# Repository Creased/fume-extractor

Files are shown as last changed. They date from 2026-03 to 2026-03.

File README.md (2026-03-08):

# Soldering Fume Extraction System

This project provides a complete set of 3D printable adapters and components to build a custom, high-efficiency fume extractor and filtration system. It integrates a VIVOSUN inline fan, a MANN-FILTER cabin air filter, and a standard 2-1/2" flexible dust collection hose.

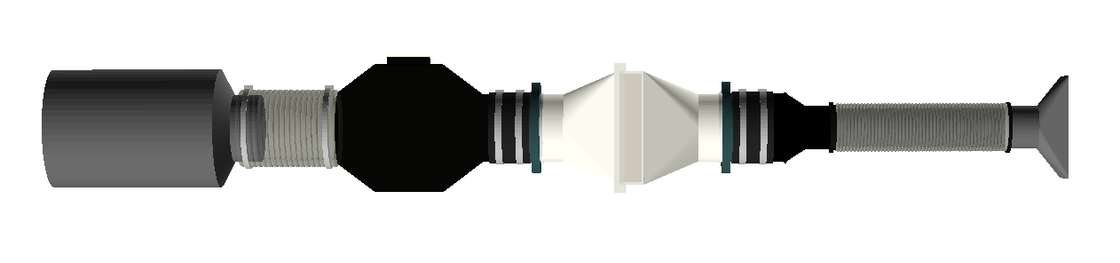
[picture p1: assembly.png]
assembly


## Bill of Materials (BOM)

### Commercial Components

| Component | Amazon FR |
| :--- | :--- |
| **VIVOSUN Inline Duct Fan Kit** (100mm, 357m³/h, Speed Controller, Carbon Filter & 240cm Duct, AeroZesh T4) | [Link](https://www.amazon.fr/dp/B0CBPDTSKS) |
| **MANN-FILTER FP 21 000-2** Cabin Air Filter (150x158x32mm) | [Link](https://www.amazon.fr/dp/B011KJG19S) |
| **PowerTec 70208V** 2-1/4" Flexible Dust Collection Hose Kit (Black, 5.7cm) | [Link](https://www.amazon.fr/dp/B09T2B5ZM2) |
| **POWERTEC 70149-P2** 4-Inch Key Hose Clamps (2 Pack) | [Link](https://www.amazon.fr/dp/B09NR8172H) |

*Note: You do not need to buy the PowerTec nozzle separately, as a customized 3D printable rectangular nozzle is provided in this repository.*

### Hardware
* **M3 Screws & Threaded Inserts**: For assembling the filter box and adapters. [Bolt Nut BT3 on AliExpress](https://fr.aliexpress.com/item/1005007615031481.html) (Requires M3x14mm Socket Head Cap Screws and M3x5mm Threaded Inserts with 4.16mm OD).

### 3D Printed Parts

The system requires the following 3D printed components:

1. **Duct Adapters** (`duct_adapter_direct.scad` & `duct_adapter.scad`)
   - **Quantity**: 2
   - **Usage**: You will generally use two **direct** variants (`duct_adapter_direct.scad`). The first adapter connects directly to the inline fan. The second adapter connects the filter box to the duct reducer. (Note: use the **threaded** variant `duct_adapter.scad` only if you wish to detach the pre-filter box from the fan and add a flexible duct section in between them).
   - Both adapters clamp around the filter box flanges using the split capture rings, providing a robust surface for the flexible hose clamps.
2. **Duct Reducer** (`duct_reducer.scad`)
   - Steps down the dimension from the 4" (100mm) top adapter to the 2-1/2" flex hose.
3. **Rectangular Nozzle & Grid** (`rectangular_nozzle.scad`)
   - Replicates the PowerTec opening but features an integrated friction-fit anti-debris grid that stops large particles without catching soldering fumes.
4. **Inline Filter Box** (`inline_filter_box.scad`)
   - The central two-part housing for the MANN-FILTER FP 21 000-2.

## Assembly Instructions

> **Tip:** Open `assembly.scad` in OpenSCAD for an exploded 3D view of how all components stack together!

1. **Print**: 3D print all `.scad` components (exporting to STL/3MF).
2. **Filter Box**: Insert the MANN-FILTER into the inline filter box housing and secure the lid with M3 hardware.
3. **Adapters**: Attach the split capture ring halves behind the filter flanges, and bolt on the adapter sleeves over them.
4. **Main Connections**: Use the POWERTEC flex hose clamps to securely connect the adapters to the duct reducer (top) and the Vivosun inline fan (bottom).
5. **Hose & Nozzle**: Push the 2-1/2" flexible hose onto the top of the duct reducer. Attach the rectangular nozzle (with its grid insert pushed into the base) to the other end of the hose.

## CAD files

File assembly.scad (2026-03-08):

// Full System Assembly
// Visualizes the complete vertical stack from suction nozzle to exhaust.

use <inline_filter_box.scad>
use <duct_adapter_direct.scad>
use <duct_reducer.scad>
use <rectangular_nozzle.scad>

$fn = 60;

// --- Options ---
assemble_all = false; // Set to true to collapse the exploded view

// Geometry Calculations
e = assemble_all ? 0 : 50;

// Filter Box (Anchor)
filter_main_z = 0;
z_filter      = filter_main_z + 3 + e;
lid_z         = filter_main_z + 35 + 2*e;

// Top Stack
top_adapter_ring_z = lid_z + 118 + 3*e;
top_adapter_z      = lid_z + 118 + 4*e;

top_joint_z        = top_adapter_z + 45 + 5*e;
top_coupling_z     = top_joint_z;
fan_z              = top_joint_z + 6*e;

exhaust_z          = fan_z + 260 + 7*e; 
carbon_filter_z    = exhaust_z + 110 + 8*e;

// Bottom Stack
bottom_adapter_ring_z = filter_main_z - 115 - 1*e;
bottom_adapter_z      = filter_main_z - 115 - 2*e;

bottom_joint_z        = bottom_adapter_z - 45 - 3*e;
bottom_coupling_z     = bottom_joint_z;

reducer_z             = bottom_joint_z - 4*e;
reducer_small_z       = reducer_z - 113.5;
top_coupler_z         = reducer_small_z + 45 - 5*e;
hose_top              = top_coupler_z - 52 - 6*e;
hose_length           = 250;
hose_bottom           = hose_top - hose_length;

bottom_coupler_z      = hose_bottom - 52 - 7*e;
nozzle_z              = bottom_coupler_z + 45 - 8*e;


// Carbon Filter
translate([0, 0, carbon_filter_z])
    carbon_filter();


// Exhaust Flex Hose (100mm)
color("DimGray", 0.4) {
    translate([0, 0, exhaust_z])
        flex_hose(d = 103, h = 150, pitch = 8); 
}
translate([0, 0, exhaust_z + 5]) metal_clamp(115);
translate([0, 0, exhaust_z + 150 - 25]) metal_clamp(115);

// Inline Fan
translate([0, 0, fan_z]) 
    vivosun_fan();


// Top Rubber Coupling
translate([0, 0, top_coupling_z]) rubber_coupling();


// Top Adapter
color("DarkSlateGray") {
    translate([0, 0, top_adapter_z]) adapter_sleeve();
    
    translate([0, 0, top_adapter_ring_z]) {
        capture_ring_half();
        mirror([1, 0, 0]) capture_ring_half();
    }
}


// Inline Filter Box
color("Wheat") {
    translate([-158/2, -150/2, z_filter]) 
        cube([158, 150, 32]);
}

color("White", 0.6) {
    translate([0, 0, filter_main_z]) build_main_body(); 
    translate([0, 0, lid_z])         build_lid(); 
}


// Bottom Adapter
color("DarkSlateGray") {
    translate([0, 0, bottom_adapter_z]) rotate([180, 0, 0]) adapter_sleeve();
    
    translate([0, 0, bottom_adapter_ring_z]) rotate([180, 0, 0]) {
        capture_ring_half();
        mirror([1, 0, 0]) capture_ring_half();
    }
}


// Bottom Rubber Coupling
translate([0, 0, bottom_coupling_z]) rubber_coupling();


// Duct Reducer (100mm to 63mm)
color("Black") {
    translate([0, 0, reducer_z])
        rotate([180, 0, 0]) duct_reducer();
}


// Suction Flex Hose (63.1mm)
color("DimGray", 0.4) {
    translate([0, 0, hose_bottom])
        flex_hose(d = 63.6, h = hose_length, pitch = 5); 
}

// Quick Couplers
translate([0, 0, top_coupler_z]) quick_coupler();
translate([0, 0, bottom_coupler_z]) rotate([180, 0, 0]) quick_coupler();


// Rectangular Nozzle
color("DimGray") {
    translate([0, 0, nozzle_z]) rotate([180, 0, 0]) {
        nozzle_body();
        color("Orange")
        translate([0, 0, 40.1 - 4]) grid_insert(); // Insert is positioned relative to base
    }
}


// Helper Modules

module flex_hose(d, h, pitch) {
    loops = floor(h / pitch);
    for (i = [0 : loops - 1]) {
        translate([0, 0, i * pitch])
            rotate_extrude()
            translate([d/2, 0])
                circle(d = pitch * 1.5, $fn = 16);
    }
}

module vivosun_fan() {
    color("Black", 0.85) {
        // Bottom flange
        cylinder(d=100, h=40);
        // Bottom transition
        translate([0,0,40]) cylinder(d1=100, d2=190, h=60);
        // Main body (contains the motor)
        translate([0,0,100]) cylinder(d=190, h=100);
        // Top transition
        translate([0,0,200]) cylinder(d1=190, d2=100, h=60);
        // Top flange
        translate([0,0,260]) cylinder(d=100, h=40);
        
        // Controller/logo box on the side
        color("DarkSlateGray") 
        translate([80, -25, 120]) cube([25, 50, 60]);
    }
}

module carbon_filter() {
    color("DimGray") {
        // Bottom Flange
        cylinder(d=100, h=40);
        // Transition
        translate([0, 0, 40]) cylinder(d1=100, d2=175, h=20);
        // Main perforated body
        color("Silver")
        translate([0, 0, 60]) cylinder(d=175, h=240);
        // Top cap
        translate([0, 0, 300]) cylinder(d=175, h=10);
    }
}

module rubber_coupling() {
    // 100mm ID, ~106mm OD, 60mm height
    translate([0, 0, -30]) { // Center it vertically
        color("#222222") 
        difference() {
            cylinder(d=106, h=60);
            translate([0,0,-1]) cylinder(d=100.2, h=62);
        }
        // Metal bands
        color("Silver") {
            translate([0,0, 10]) difference() { cylinder(d=108, h=10); translate([0,0,-1]) cylinder(d=105, h=12); }
            translate([0,0, 40]) difference() { cylinder(d=108, h=10); translate([0,0,-1]) cylinder(d=105, h=12); }
            // Worm gear housing representations
            translate([53, 0, 15]) rotate([90,0,0]) cube([8, 12, 10], center=true);
            translate([53, 0, 45]) rotate([90,0,0]) cube([8, 12, 10], center=true);
        }
    }
}

module metal_clamp(id=105) {
    color("Silver") {
        difference() { cylinder(d=id+4, h=8); translate([0,0,-0.1]) cylinder(d=id, h=8.2); }
        // Worm gear screw housing
        translate([id/2 + 2, 0, 4]) rotate([90,0,0]) cube([8, 12, 10], center=true);
    }
}

module quick_coupler() {
    color("#111111") {
        // Upper smooth insert (goes into duct_reducer / nozzle)
        translate([0, 0, -45]) cylinder(d=58, h=45);
        
        // Stopper flange
        translate([0, 0, -50]) cylinder(d=75, h=5);
        translate([0, 0, -52]) cylinder(d=67, h=2);
        
        // Lower threaded part (screws onto the hose)
        translate([0, 0, -85]) cylinder(d=67, h=33);
    }
}

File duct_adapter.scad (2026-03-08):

// Duct Adapter - 3-Piece System (Threaded)
// ==============================================
// Problem: Printed filter box has a 106mm OD flange with a 110mm lip.
//          The 100mm flex duct can't slide over the lip.
//
// Solution:
//   1. SPLIT CAPTURE RING (x2 halves) - Fits around the flange behind
//      the lip. Threaded inserts on the back face.
//   2. ADAPTER SLEEVE - Bolts through its flange plate into the ring
//      inserts, holding both ring halves AND the sleeve in place.
//      The flex duct screws OVER the sleeve tube via spiral thread.
//
// The sleeve bolts span BOTH ring halves, so no lugs are needed!

// --- Existing printed part dimensions ---
existing_flange_od = 106;     // Flange tube OD
existing_lip_od = 110;        // Retention lip OD
existing_lip_length = 5;      // Lip axial length
existing_flange_length = 35;  // Total flange length (ghost only)

// --- General ---
clearance = 0.4;
wall = 3;

// --- Capture Ring ---
ring_body_width = 12;         // Radial wall thickness
ring_depth = 12;              // Total axial depth (tuned for 14mm screws)
groove_depth = 6;             // Groove depth for the lip

// --- Adapter Sleeve ---
duct_diameter = 100;
duct_fit_clearance = 3;       // Tube = 97mm, slides easily into 100mm duct
sleeve_length = 40;
sleeve_wall = 3;
sleeve_flange = 5;            // Flange plate thickness (must be > screw_head_depth)

// --- Thread on sleeve tube (for screwing the duct on) ---
thread_pitch = 12;            // Matches spacing between duct wire guides
thread_ridge_height = 1.5;    // Ridge OD = 97 + 2*1.5 = 100mm, matches duct ID exactly
thread_turns = 3;             // Number of spiral turns
thread_width = 6;             // Cross-section width of the ridge (leaves 6mm gap in 12mm pitch)

// --- Hardware ---
bolt_hole_diameter = 3.5;
insert_diameter = 4.16;
insert_depth = 5;
screw_head_diameter = 5.3;
screw_head_depth = 3;
num_sleeve_bolts = 6;         // MUST be even so bolts are symmetric on both halves

$fn = 100;

// --- Calculated Dimensions ---
ring_back_id = existing_flange_od + clearance;
ring_front_id = existing_lip_od + clearance;
ring_od = ring_front_id + 2 * ring_body_width;

sleeve_od = duct_diameter - duct_fit_clearance;
sleeve_id = sleeve_od - 2 * sleeve_wall;
// Bolt circle sits in the middle of the ring wall
sleeve_bolt_circle_r = (ring_front_id + ring_od) / 4; // radius, not diameter

// --- Display Mode ---
show_assembled = false;        // true = verify fit, false = print layout

if (show_assembled) {
    // Ghost of the existing flange (transparent reference)
    %ghost_flange();

    // Ring halves: assembled behind the lip
    translate([0, 0, -(ring_depth - groove_depth)]) {
        capture_ring_half();
        mirror([1, 0, 0]) capture_ring_half();
    }

    // Sleeve: bolts onto the ring front face
    translate([0, 0, groove_depth])
        adapter_sleeve();

} else {
    // Print layout
    translate([0, ring_od/2 + 10, 0]) capture_ring_half();
    translate([0, -(ring_od/2 + 10), 0]) mirror([0, 1, 0]) capture_ring_half();
    translate([ring_od + 30, 0, 0]) adapter_sleeve();
}


// ==========================================
// MODULES
// ==========================================

// One half of the capture ring (semicircle, X+ side)
module capture_ring_half() {
    difference() {
        union() {
            // Back section: narrower bore, hooks behind the lip
            half_ring(ring_back_id, ring_od, ring_depth - groove_depth);

            // Front section: wider bore, accommodates the lip
            translate([0, 0, ring_depth - groove_depth])
                half_ring(ring_front_id, ring_od, groove_depth);
        }

        // Sleeve bolt holes through the ring body.
        // Inserts on BACK face (Z=0), clearance from insert to front.
        for (i = [0 : num_sleeve_bolts - 1]) {
            angle = i * (360 / num_sleeve_bolts);
            bx = sleeve_bolt_circle_r * cos(angle);
            by = sleeve_bolt_circle_r * sin(angle);
            if (bx > 0.1) {
                // Insert hole on back face (Z=0)
                translate([bx, by, -0.1])
                    cylinder(d = insert_diameter, h = insert_depth + 0.1);
                // Clearance hole from insert to front face
                translate([bx, by, insert_depth])
                    cylinder(d = bolt_hole_diameter, h = ring_depth - insert_depth + 0.1);
            }
        }
    }
}

// Helper: a semicircular ring (X+ half only)
module half_ring(id, od, h) {
    difference() {
        cylinder(d = od, h = h);
        translate([0, 0, -0.1])
            cylinder(d = id, h = h + 0.2);
        // Remove X- half
        translate([-od, -od/2, -0.1])
            cube([od, od, h + 0.2]);
    }
}

// Adapter sleeve: flange + threaded tube. Bolts hold ring halves together.
module adapter_sleeve() {
    difference() {
        union() {
            // Flange plate (spans both ring halves)
            cylinder(d = ring_od, h = sleeve_flange);

            // Tube for flex duct
            translate([0, 0, sleeve_flange])
                cylinder(d = sleeve_od, h = sleeve_length);

            // Spiral thread on the tube (duct screws on by twisting)
            translate([0, 0, sleeve_flange])
                spiral_thread(sleeve_od, thread_pitch, thread_ridge_height, thread_width, thread_turns);
        }

        // Hollow centre
        translate([0, 0, -0.1])
            cylinder(d = sleeve_id, h = sleeve_flange + sleeve_length + 0.2);

        // Bolt holes (clearance + counterbore)
        for (i = [0 : num_sleeve_bolts - 1]) {
            angle = i * (360 / num_sleeve_bolts);
            translate([sleeve_bolt_circle_r * cos(angle), sleeve_bolt_circle_r * sin(angle), 0]) {
                // Clearance hole
                translate([0, 0, -0.1])
                    cylinder(d = bolt_hole_diameter, h = sleeve_flange + 0.2);
                // Counterbore for screw head (on the outer face)
                translate([0, 0, sleeve_flange - screw_head_depth])
                    cylinder(d = screw_head_diameter, h = screw_head_depth + 0.1);
            }
        }
    }
}

// Ghost of the existing printed flange (transparent reference)
module ghost_flange() {
    flange_bore = existing_flange_od - 2 * 3;
    difference() {
        union() {
            translate([0, 0, -existing_flange_length + existing_lip_length])
                cylinder(d = existing_flange_od, h = existing_flange_length);
            cylinder(d = existing_lip_od, h = existing_lip_length);
        }
        translate([0, 0, -existing_flange_length + existing_lip_length - 0.1])
            cylinder(d = flange_bore, h = existing_flange_length + 0.2);
    }
}

// Spiral thread ridge on a tube surface.
// Creates a helical ridge that the flex duct grips when twisted on.
// Thread direction: LEFT-HAND (matches duct wire direction)
module spiral_thread(tube_od, pitch, ridge_h, ridge_w, turns) {
    thread_length = turns * pitch;
    segments_per_turn = 36;
    total_segments = turns * segments_per_turn;
    
    for (i = [0 : total_segments - 1]) {
        angle1 = -(i * 360 / segments_per_turn);
        angle2 = -((i + 1) * 360 / segments_per_turn);
        z1 = i * pitch / segments_per_turn;
        z2 = (i + 1) * pitch / segments_per_turn;
        r = tube_od / 2 + ridge_h / 2;
        
        hull() {
            translate([r * cos(angle1), r * sin(angle1), z1])
                sphere(d = ridge_w, $fn = 12);
            translate([r * cos(angle2), r * sin(angle2), z2])
                sphere(d = ridge_w, $fn = 12);
        }
    }
}

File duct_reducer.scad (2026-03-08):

// Duct Reducer - 4" to 2-1/2"
// Replica of Powertec 70136 style reducer.
// Both ends slide inside the ducting.

// Dimensions (mm)
// Small end (2-1/2" duct)
small_od = 63.1;              // 2 31/64" OD
small_id = 58.7;              // 2 5/16" ID
small_tube_length = 34.9;     // 1 3/8"

// Large end (4" duct)
large_od = 100.4;             // 3 61/64" OD
large_id = 93.3;              // 3 43/64" ID
large_tube_length = 50.0;     // 1 31/32"

// Overall
total_height = 113.5;         // 4 15/32"

// Wall thickness (derived from dimensions)
wall = (small_od - small_id) / 2;  // ~2.2mm

// Calculated
cone_height = total_height - small_tube_length - large_tube_length;

// Lip/step at each end (prevents duct from sliding too far)
lip_height = 3;
lip_extra = 2;                // How much the lip extends beyond the tube OD

$fn = 100;

// Build the reducer
module duct_reducer() {
    difference() {
    union() {
        // Large tube (bottom)
        cylinder(d = large_od, h = large_tube_length);
        
        // Lip/step at large tube/cone junction (duct stop)
        translate([0, 0, large_tube_length - lip_height])
            cylinder(d = large_od + 2 * lip_extra, h = lip_height);
        
        // Conical transition
        translate([0, 0, large_tube_length])
            cylinder(d1 = large_od, d2 = small_od, h = cone_height);
        
        // Small tube (top)
        translate([0, 0, large_tube_length + cone_height])
            cylinder(d = small_od, h = small_tube_length);
    }
    
    // Hollow out the inside 
    // Large bore
    translate([0, 0, -1])
        cylinder(d = large_id, h = large_tube_length + 2);
    
    // Conical bore
    translate([0, 0, large_tube_length - 0.1])
        cylinder(d1 = large_id, d2 = small_id, h = cone_height + 0.2);
    
    // Small bore
    translate([0, 0, large_tube_length + cone_height - 0.1])
        cylinder(d = small_id, h = small_tube_length + 2);
    }
}

duct_reducer();

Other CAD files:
duct_adapter_direct.scad
inline_filter_box.scad
rectangular_nozzle.scad

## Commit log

2026-03-08 Initial commit of fume extractor designs
    [assembly.scad, duct_adapter.scad, duct_adapter_direct.scad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]
2026-03-08 Add assembly
